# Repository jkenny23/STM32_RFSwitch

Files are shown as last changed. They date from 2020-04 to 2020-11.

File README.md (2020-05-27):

# STM32_RFSwitch
12V RF switch/DC relay controller (7 channels) and open-drain button press emulator (6 channels) with switchable USB2.0/USB3.0 ports with independent voltage/current monitoring. Includes 2 thermistor channels, and 2 spare ADC, 2 spare GPIO, and 1 spare GPI channel.

Zip file contains Gerbers ready for fab (2-up panel), and xlsx files contain BOM/component placement list also needed for fab by JLCPCB SMT service. Estimated cost is $61.77 for PCBA including DHL shipping (10 boards total, 5 panels), plus $18.12 for additional components from LCSC (through hole headers, inductor, USB connectors), and $16.86 for the STM32 "blue pill" microcontroller boards, for a total of $96.75 ($9.68 per board).

Usage:

RF Switch: r[1-7]

USB2.0 Power Control: l[1-2, 1=off, 2=on]

USB3.0 Power Control:  m[1-2, 1=off, 2=on]

Open Drain Output: o[1-6] l[level: 0 = open, 1 = low, default 0] d[delay, x0.1s, deafult 10 (1s)]

Cal R/W Mode: t[r/w] a[address: 0-999] d[data, unsigned int (0-65535)]

Version: v

Status: s

Soft Reset: z

Help (Prints this menu): ?

# Compatible RF Switches

| RF Switch P/N | RF Switch Mfg. | RF Switch Config | # IOs | CH/CL | Notes | RF Switch Datasheet | Approx. Price |
|---|---|---|---|---|---|---|---|
| 2SE1T11JB | Ducommun | SPDT | 2 | CL | | https://www.ducommun.com/pdf/mwcat/2s.pdf | $18.75-20 |
| 431-420823 | Dow-Key | SP3T | 3 | CH | Remove pull up resistor (R5/R15/R19/R25/R38/R47/R55) for IOs used | https://www.dowkey.com/wp-content/uploads/2015/06/_plk49_1_431461_Latching_CatalogPage.pdf | ~$36 (similar models) |

# Errata
The +/- input are swapped for the MCP6002 op-amp 2 (USB3.0 current measurement). The traces need to be cut and jumpered per the image below:

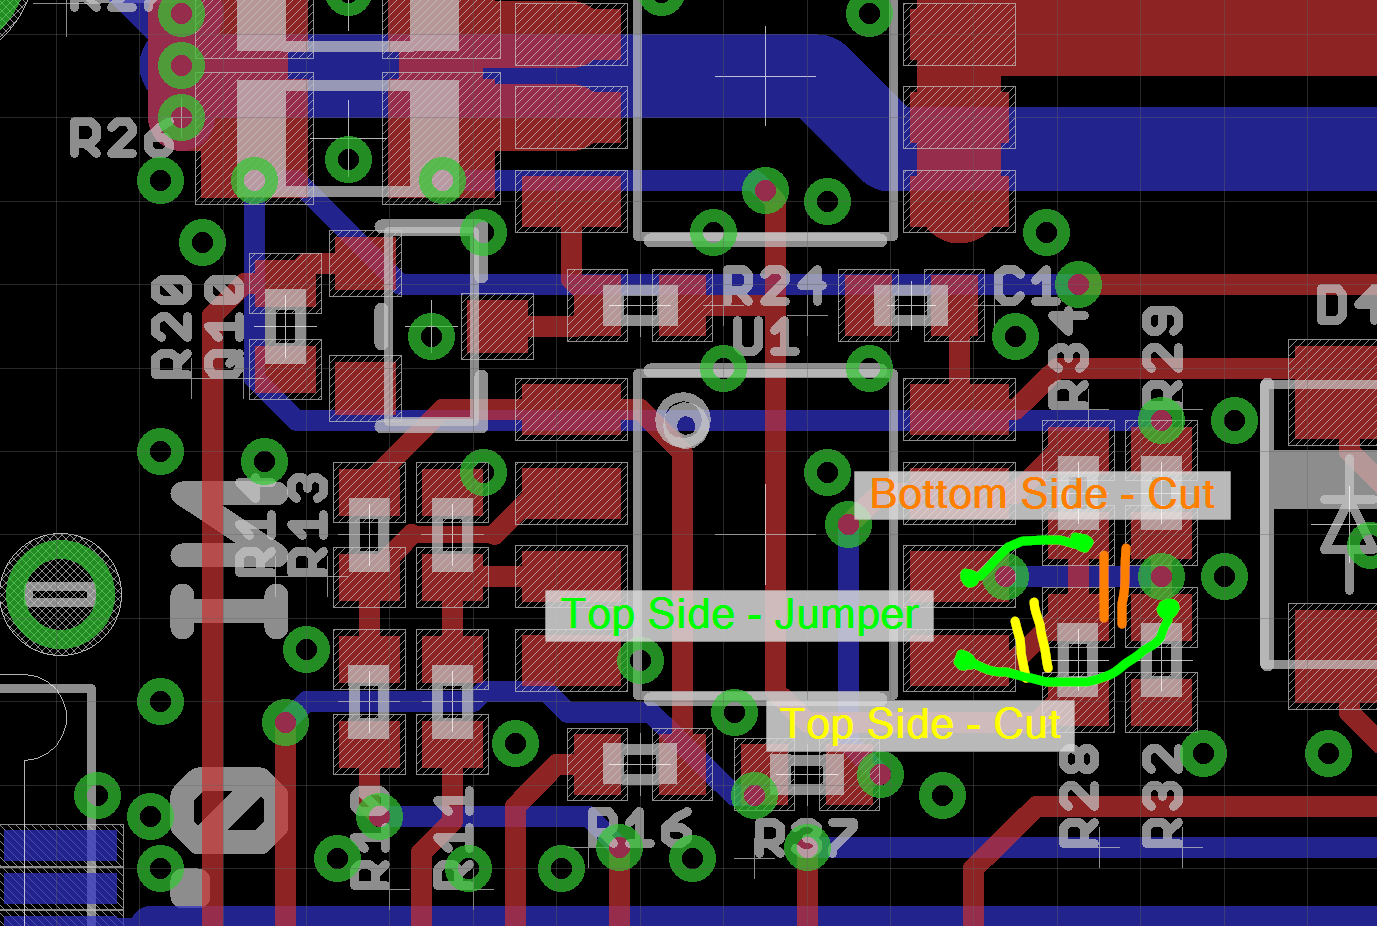
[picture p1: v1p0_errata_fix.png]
HW Fix for v1.0


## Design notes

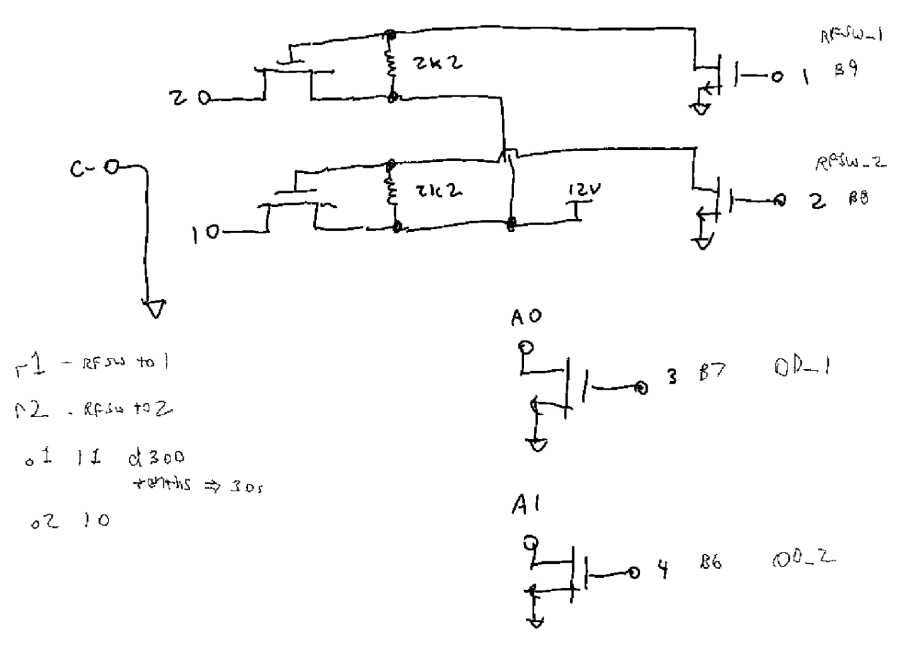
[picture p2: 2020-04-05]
RFSwitch_Schematic_Sketch.png

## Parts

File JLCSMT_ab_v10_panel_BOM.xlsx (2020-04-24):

Comment | Designator | Footprint | LCSC Part #（optional）
1.8k | R42, R60 | 0402_R | C4177
1k | R10, R11, R28, R29, R43, R46, R49, R51, R54, R57, R62, R69, R71, R74, R75, R76, R77, R78, R90, R92 | 0402_R | C11702
1u | C1, C3, C5, C11, C16, C17, C18, C20, C21, C23, C24, C25, C26, C33 | 0402_C | C52923
2.7k | R40, R67 | 0402_R | C13167
2N7002 | Q4, Q10, Q15, Q17, Q19, Q20, Q22, Q24, Q25, Q27, Q28, Q29, Q30, Q31, Q32, Q35 | SOT-23 | C8545
4.7u | C19, C22 | 0402_C | C23733
8.2k | R3, R21, R64, R88 | 0402_R | C25924
10k | R1, R2, R4, R5, R6, R9, R12, R15, R16, R17, R19, R20, R22, R23, R24, R25, R30, R31, R36, R37, R38, R41, R44, R45, R47, R48, R50, R52, R53, R55, R56, R59, R63, R65, R79, R80, R81, R82, R83, R84, R85, R87, R89, R95, R96, R97, R98, R99, R100, R101, R102, R103, R104, R105, R106, R107, R108, R109, R110, R111, R112, R114 | 0402_R | C25744
10n | C4, C14, C34, C35 | 0402_C | C15195
10u | C7, C8, C29, C30 | 0603_C | C19702
10u | C13, C15, C31, C32 | 0805_C | C15850
20k | R13, R14, R32, R34, R35, R68, R70, R72, R91, R93 | 0402_R | C25765
22n | C2, C6, C10, C36, C37, C38 | 0402_C | C1532
33k | R33, R113 | 0402_R | C25779
51k | R39, R66 | 0402_R | C25794
100m | R7, R8, R26, R27, R61, R73, R86, R94 | 1206_R | C25334
100n | C9, C12, C27, C28 | 0402_C | C1525
120 | R18, R58 | 0402_R | C25079
AO3400A | Q2, Q6, Q8, Q12, Q14, Q18, Q23, Q36, Q38, Q40, Q42, Q44, Q46, Q48 | SOT-23 | C20917
AO3401A | Q1, Q5, Q7, Q11, Q13, Q16, Q21, Q33, Q37, Q39, Q41, Q43, Q45, Q47 | SOT-23 | C15127
AO4407A | Q3, Q9, Q26, Q34 | SOIC-8 | C16072
B5817W | D1, D5, D6, D10, D12, D13, D14, D22, D23, D24, D25, D26, D27, D28 | SOD123 | C8598
CJ431 | U2, U6 | SOT-23 | C3113
FP6291 | U4, U9 | SOT-23-6 | C18701
MCP6002SOIC | U1, U10 | SOIC-8 | C7377
SS14 | D2, D3, D4, D15, D16, D17 | SMA | C2480
SS34 | D7, D8, D9, D11, D18, D19, D20, D21 | SMA | C8678

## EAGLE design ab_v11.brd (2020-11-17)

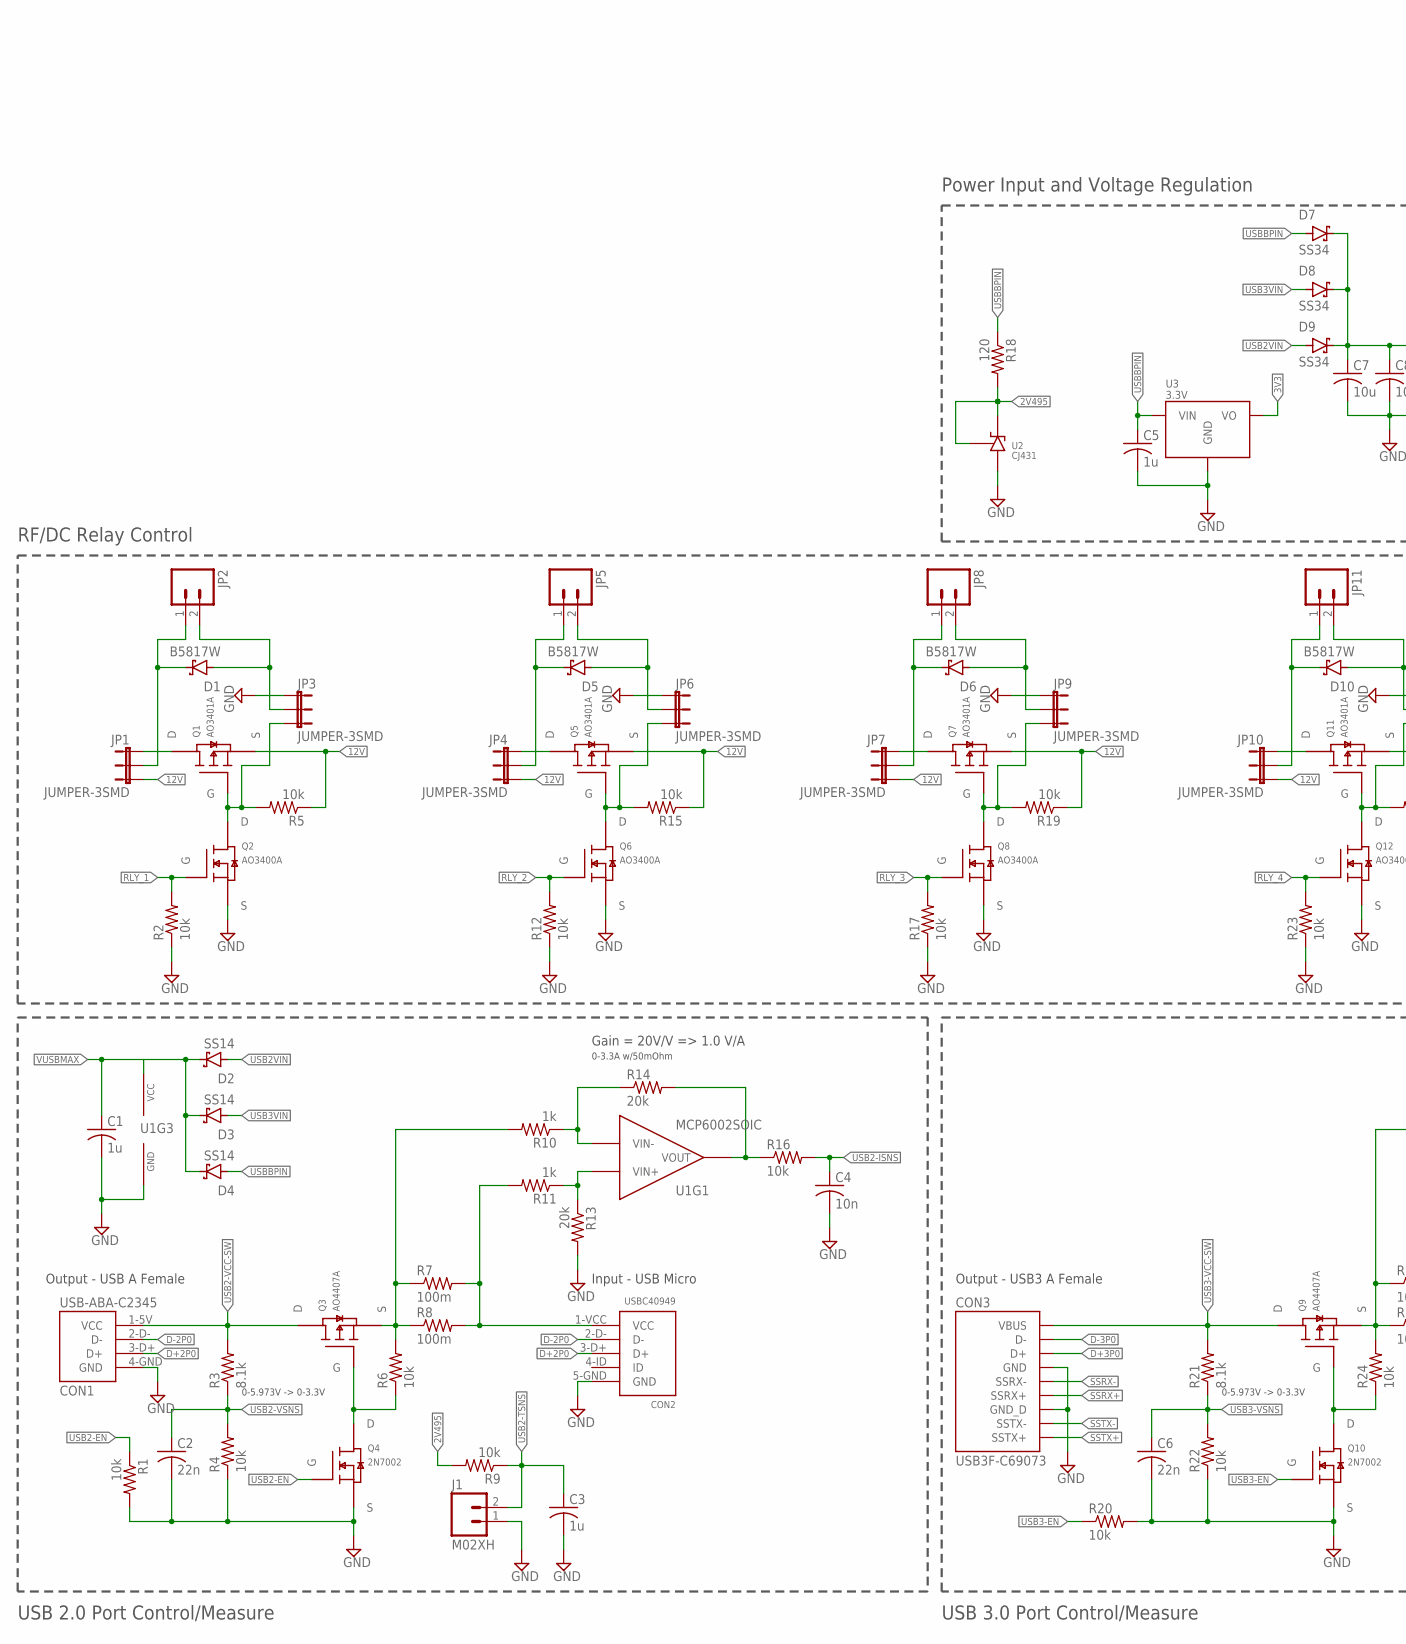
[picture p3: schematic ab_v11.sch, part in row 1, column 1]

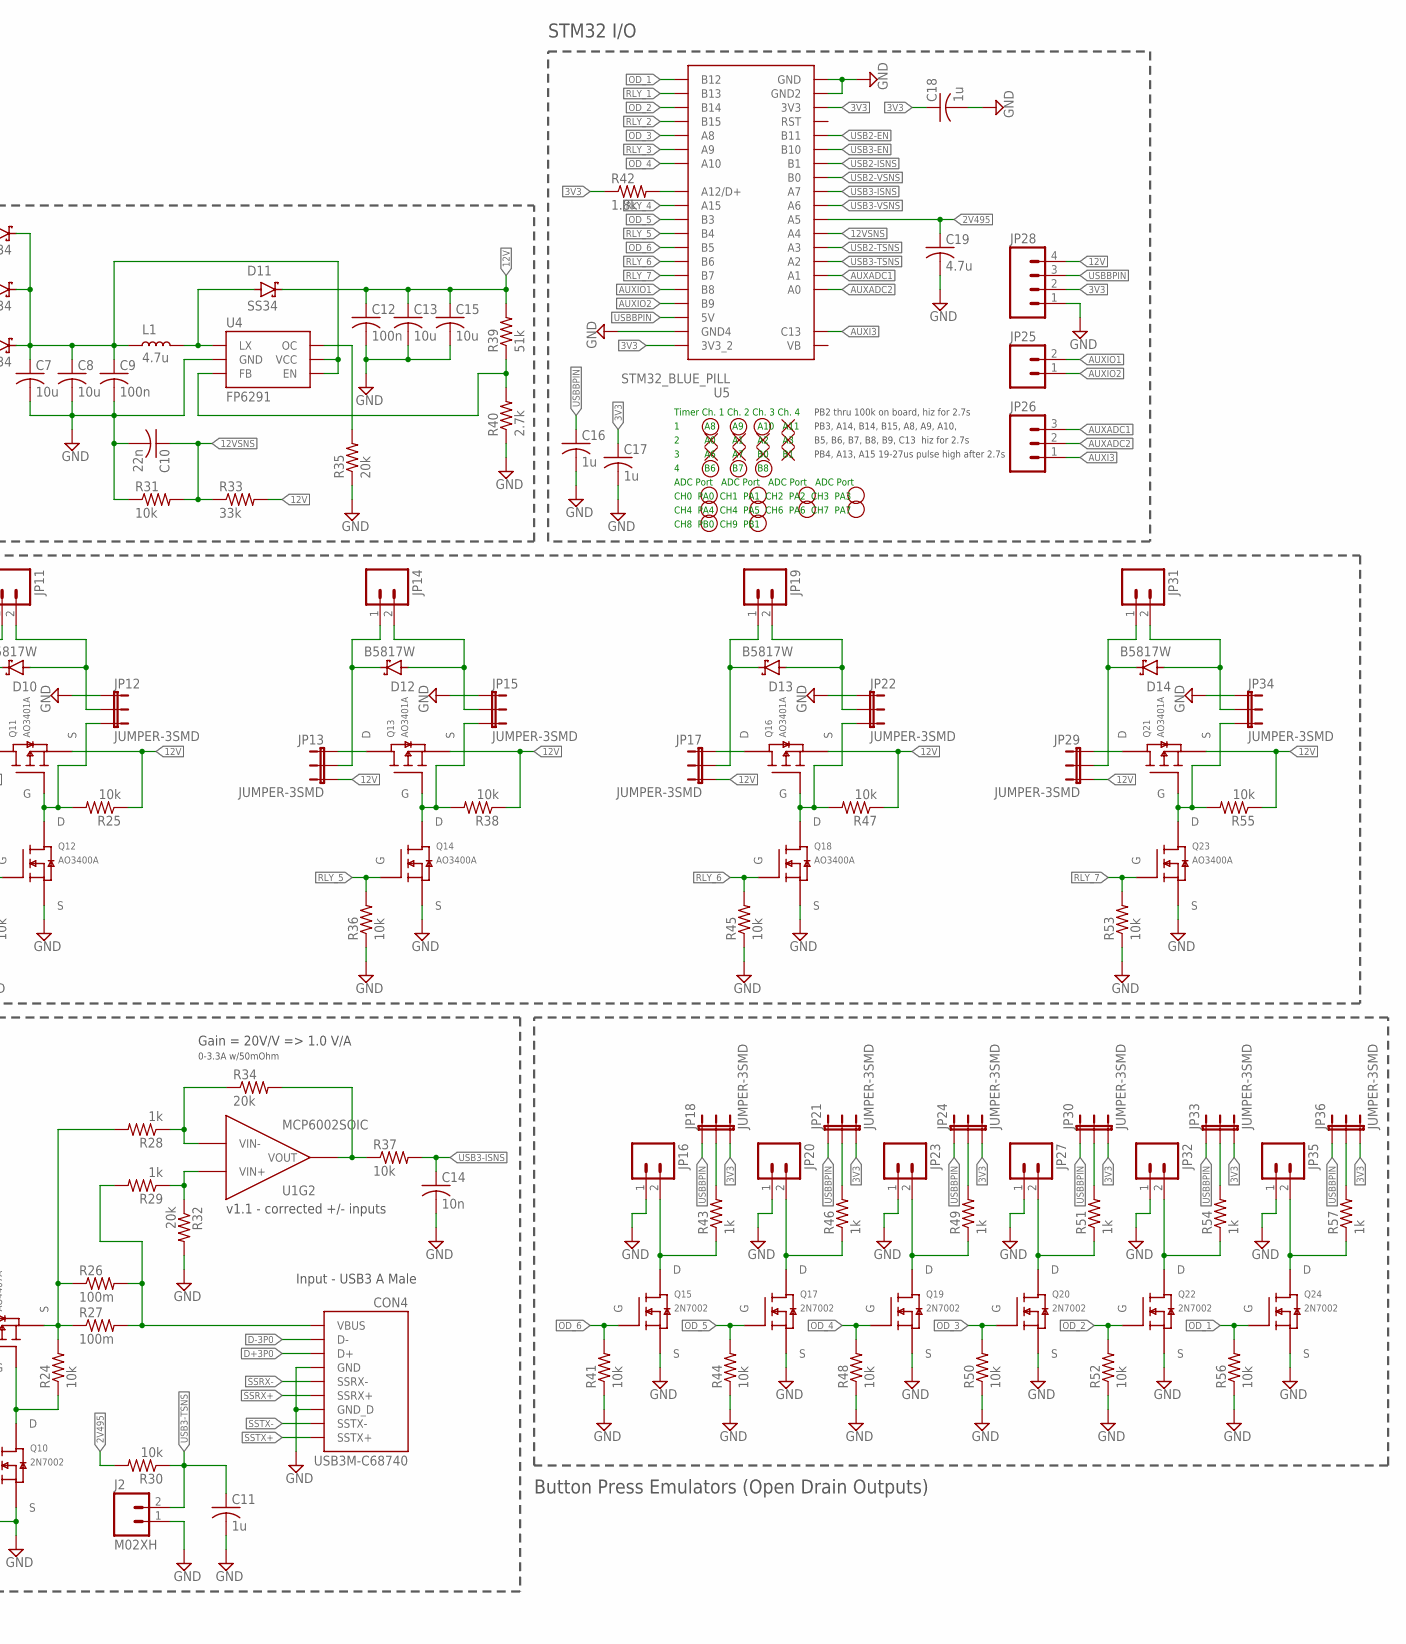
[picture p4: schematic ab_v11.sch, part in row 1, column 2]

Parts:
C1, C3, C5, C11, C16, C17, C18: 1u; C0402
C2, C6, C10: 22n; C0402
C4, C14: 10n; C0402
C7, C8: 10u; C0603
C9, C12: 100n; C0402
C13, C15: 10u; C0805
C19: 4.7u; C0402
CON1: USB-ABA-C2345; USB_A_C2345
CON2: USBC40949; MICRO_USB-B_C40949
CON3: USB3F-C69073; USB3-F-C69073
CON4: USB3M-C68740; USB3-M-C68740
D1, D5, D6, D10, D12, D13, D14: B5817W; SOD123W
D2, D3, D4: SS14; SMA
D7, D8, D9, D11: SS34; SMA
J1, J2: M02XH; B2B-XH-A
JP1, JP3, JP4, JP6, JP7, JP9, JP10, JP12, JP13, JP15, JP17, JP18, JP21, JP22, JP24, JP29, JP30, JP33, JP34, JP36: JUMPER-3SMD; SJ_3
JP2, JP5, JP8, JP11, JP14, JP16, JP19, JP20, JP23, JP25, JP27, JP31, JP32, JP35: M02PTH; 1X02
JP26: M03PTH; 1X03
JP28: M04PTH; 1X04
L1: 4.7u; INDUCTOR_6X6
Q1, Q5, Q7, Q11, Q13, Q16, Q21: AO3401A; SOT23
Q2, Q6, Q8, Q12, Q14, Q18, Q23: AO3400A; SOT23
Q3, Q9: AO4407A; 8-SOIC
Q4, Q10, Q15, Q17, Q19, Q20, Q22, Q24: 2N7002; SOT23
R1, R2, R4, R5, R6, R9, R12, R15, R16, R17, R19, R20, R22, R23, R24, R25, R30, R31, R36, R37, R38, R41, R44, R45, R47, R48, R50, R52, R53, R55, R56: 10k; R0402
R3, R21: 8.1k; R0402
R7, R8, R26, R27: 100m; R1206
R10, R11, R28, R29, R43, R46, R49, R51, R54, R57: 1k; R0402
R13, R14, R32, R34, R35: 20k; R0402
R18: 120; R0402
R33: 33k; R0402
R39: 51k; R0402
R40: 2.7k; R0402
R42: 1.8k; R0402
U1: MCP6002SOIC; 8-SOIC
U2: CJ431; SOT23
U3: 3.3V; SOT-89
U4: FP6291; SOT23-6
U5: STM32_BLUE_PILL; STM32_BLUE_PILL_USABLE

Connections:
2V495: C19.1, R9.2, R18.2, R30.2, U2.1 (K), U2.2 (REF), U5.A5
3V3: C17.1, C18.1, JP18.3, JP21.3, JP24.3, JP28.2, JP30.3, JP33.3, JP36.3, R42.1, U3.1 (VO), U5.3V3, U5.3V3_2
12V: C12.1, C13.1, C15.1, D11.K (CATHODE), JP1.3, JP4.3, JP7.3, JP10.3, JP13.3, JP17.3, JP28.4, JP29.3, Q1.2 (S), Q5.2 (S), Q7.2 (S), Q11.2 (S), Q13.2 (S), Q16.2 (S), Q21.2 (S), R5.1, R15.1, R19.1, R25.1, R33.2, R38.1, R39.2, R47.1, R55.1
12VSNS: C10.1, R31.2, R33.1, U5.A4
AUXADC1: JP26.3, U5.A1
AUXADC2: JP26.2, U5.A0
AUXI3: JP26.1, U5.C13
AUXIO1: JP25.2, U5.B8
AUXIO2: JP25.1, U5.B9
BOOSTVCC: C7.1, C8.1, C9.1, D7.K (CATHODE), D8.K (CATHODE), D9.K (CATHODE), L1.1, U4.4 (EN), U4.5 (VCC)
D+2P0: CON1.3-D+ (D+), CON2.3-D+ (D+)
D+3P0: CON3.3-D+ (D+), CON4.3-D+ (D+)
D-2P0: CON1.2-D- (D-), CON2.2-D- (D-)
D-3P0: CON3.2-D- (D-), CON4.2-D- (D-)
FB: R39.1, R40.2, U4.3 (FB)
GND: C1.2, C2.2, C3.2, C4.2, C5.2, C6.2, C7.2, C8.2, C9.2, C10.2, C11.2, C12.2, C13.2, C14.2, C15.2, C16.2, C17.2, C18.2, C19.2, CON1.4-GND (GND), CON2.5-GND (GND), CON3.4-GND (GND), CON3.7-GND (GND_D), CON4.4-GND (GND), CON4.7-GNDD (GND_D), J1.1, J2.1, JP3.1, JP6.1, JP9.1, JP12.1, JP15.1, JP16.1, JP20.1, JP22.1, JP23.1, JP27.1, JP28.1, JP32.1, JP34.1, JP35.1, Q2.2 (S), Q4.2 (S), Q6.2 (S), Q8.2 (S), Q10.2 (S), Q12.2 (S), Q14.2 (S), Q15.2 (S), Q17.2 (S), Q18.2 (S), Q19.2 (S), Q20.2 (S), Q22.2 (S), Q23.2 (S), Q24.2 (S), R1.2, R2.1, R4.1, R12.1, R13.2, R17.1, R20.2, R22.1, R23.1, R31.1, R32.2, R35.1, R36.1, R40.1, R41.1, R44.1, R45.1, R48.1, R50.1, R52.1, R53.1, R56.1, U1.4 (GND), U2.3 (A), U3.2 (GND), U3.2@1 (GND), U4.2 (GND), U5.GND, U5.GND2, U5.GND4
unnamed: JP16.2, Q15.3 (D), R43.1
unnamed: Q9.4 (G), Q10.3 (D), R24.1
unnamed: R10.1, R14.1, U1.2 (VIN-)
unnamed: R11.1, R13.1, U1.3 (VIN+)
unnamed: JP21.2, R46.2
unnamed: JP18.2, R43.2
unnamed: Q3.4 (G), Q4.3 (D), R6.1
unnamed: JP20.2, Q17.3 (D), R46.1
unnamed: JP24.2, R49.2
unnamed: JP23.2, Q19.3 (D), R49.1
unnamed: JP30.2, R51.2
unnamed: JP27.2, Q20.3 (D), R51.1
unnamed: JP33.2, R54.2
unnamed: JP32.2, Q22.3 (D), R54.1
unnamed: JP36.2, R57.2
unnamed: R28.1, R34.1, U1.6 (VIN-)
unnamed: R29.1, R32.1, U1.5 (VIN+)
unnamed: JP35.2, Q24.3 (D), R57.1
unnamed: JP6.3, Q5.1 (G), Q6.3 (D), R15.2
unnamed: R42.2, U5.A12 (A12/D+)
OC: R35.2, U4.6 (OC)
OD_1: Q24.1 (G), R56.2, U5.B12
OD_2: Q22.1 (G), R52.2, U5.B14
OD_3: Q20.1 (G), R50.2, U5.A8
OD_4: Q19.1 (G), R48.2, U5.A10
OD_5: Q17.1 (G), R44.2, U5.B3
OD_6: Q15.1 (G), R41.2, U5.B5
RLY1-SW: D1.K (CATHODE), JP1.2, JP2.1
RLY1-SW1: D5.K (CATHODE), JP4.2, JP5.1
RLY1-SW2: D6.K (CATHODE), JP7.2, JP8.1
RLY1-SW3: D10.K (CATHODE), JP10.2, JP11.1
RLY1-SW4: D12.K (CATHODE), JP13.2, JP14.1
RLY1-SW5: D13.K (CATHODE), JP17.2, JP19.1
RLY1-SW6: D14.K (CATHODE), JP29.2, JP31.1
RLY1D: JP1.1, Q1.3 (D)
RLY1D1: JP4.1, Q5.3 (D)
RLY1D2: JP7.1, Q7.3 (D)
RLY1D3: JP10.1, Q11.3 (D)
RLY1D4: JP13.1, Q13.3 (D)
RLY1D5: JP17.1, Q16.3 (D)
RLY1D6: JP29.1, Q21.3 (D)
RLY1DG: JP3.3, Q1.1 (G), Q2.3 (D), R5.2
RLY1DG2: JP9.3, Q7.1 (G), Q8.3 (D), R19.2
RLY1DG3: JP12.3, Q11.1 (G), Q12.3 (D), R25.2
RLY1DG4: JP15.3, Q13.1 (G), Q14.3 (D), R38.2
RLY1DG5: JP22.3, Q16.1 (G), Q18.3 (D), R47.2
RLY1DG6: JP34.3, Q21.1 (G), Q23.3 (D), R55.2
RLY1SPLY: D1.A (ANODE), JP2.2, JP3.2
RLY1SPLY1: D5.A (ANODE), JP5.2, JP6.2
RLY1SPLY2: D6.A (ANODE), JP8.2, JP9.2
RLY1SPLY3: D10.A (ANODE), JP11.2, JP12.2
RLY1SPLY4: D12.A (ANODE), JP14.2, JP15.2
RLY1SPLY5: D13.A (ANODE), JP19.2, JP22.2
RLY1SPLY6: D14.A (ANODE), JP31.2, JP34.2
RLY_1: Q2.1 (G), R2.2, U5.B13
RLY_2: Q6.1 (G), R12.2, U5.B15
RLY_3: Q8.1 (G), R17.2, U5.A9
RLY_4: Q12.1 (G), R23.2, U5.A15
RLY_5: Q14.1 (G), R36.2, U5.B4
RLY_6: Q18.1 (G), R45.2, U5.B6
RLY_7: Q23.1 (G), R53.2, U5.B7
SSRX+: CON3.6-SSRX+ (SSRX+), CON4.6-SSRX+ (SSRX+)
SSRX-: CON3.5-SSRX- (SSRX-), CON4.5-SSRX- (SSRX-)
SSTX+: CON3.9-SSTX+ (SSTX+), CON4.9-SSTX+ (SSTX+)
SSTX-: CON3.8-SSTX- (SSTX-), CON4.8-SSTX- (SSTX-)
SW: D11.A (ANODE), L1.2, U4.1 (LX)
USB2-EN: Q4.1 (G), R1.1, U5.B11
USB2-ISNS: C4.1, R16.2, U5.B1
USB2-ISNS-R: R14.2, R16.1, U1.1 (VOUT)
USB2-TSNS: C3.1, J1.2, R9.1, U5.A3
USB2-VCC-SW: CON1.1-5V (VCC), Q3.5 (D), Q3.6 (D), Q3.7 (D), Q3.8 (D), R3.2
USB2-VSNS: C2.1, R3.1, R4.2, U5.B0
USB2VIN: CON2.1-VCC (VCC), D2.A (ANODE), D9.A (ANODE), R7.2, R8.2, R11.2
USB3-EN: Q10.1 (G), R20.1, U5.B10
USB3-ISNS: C14.1, R37.2, U5.A7
USB3-ISNS-R: R34.2, R37.1, U1.7 (VOUT)
USB3-TSNS: C11.1, J2.2, R30.1, U5.A2
USB3-VCC-SW: CON3.1-VBUS (VBUS), Q9.5 (D), Q9.6 (D), Q9.7 (D), Q9.8 (D), R21.2
USB3-VSNS: C6.1, R21.1, R22.2, U5.A6
USB3OUTVCC: Q9.1 (S), Q9.2 (S), Q9.3 (S), R24.2, R26.1, R27.1, R28.2
USB3VIN: CON4.1-VBUS (VBUS), D3.A (ANODE), D8.A (ANODE), R26.2, R27.2, R29.2
USBBPIN: C5.1, C16.1, D4.A (ANODE), D7.A (ANODE), JP18.1, JP21.1, JP24.1, JP28.3, JP30.1, JP33.1, JP36.1, R18.1, U3.3 (VIN), U5.5V
USBOUTVCC: Q3.1 (S), Q3.2 (S), Q3.3 (S), R6.2, R7.1, R8.1, R10.2
VUSBMAX: C1.1, D2.K (CATHODE), D3.K (CATHODE), D4.K (CATHODE), U1.8 (VCC)

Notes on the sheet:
Gain = 20V/V => 1.0 V/A
0-3.3A w/50mOhm
0-5.973V -> 0-3.3V
STM32 I/O
Timer Ch. 1 Ch. 2 Ch. 3 Ch. 4
1 A8 A9 A10 A11
2 A0 A1 A2 A3
3 A6 A7 B0 B1
4 B6 B7 B8
ADC Port ADC Port ADC Port ADC Port
CH0 PA0 CH1 PA1 CH2 PA2 CH3 PA3
CH4 PA4 CH4 PA5 CH6 PA6 CH7 PA7
CH8 PB0 CH9 PB1
PB2 thru 100k on board, hiz for 2.7s
PB3, A14, B14, B15, A8, A9, A10,
PB4, A13, A15 19-27us pulse high after 2.7s
B5, B6, B7, B8, B9, C13 hiz for 2.7s
USB 2.0 Port Control/Measure
Power Input and Voltage Regulation
Button Press Emulators (Open Drain Outputs)
Input - USB Micro
Output - USB A Female
USB 3.0 Port Control/Measure
Input - USB3 A Male
Output - USB3 A Female
RF/DC Relay Control
v1.1 - corrected +/- inputs

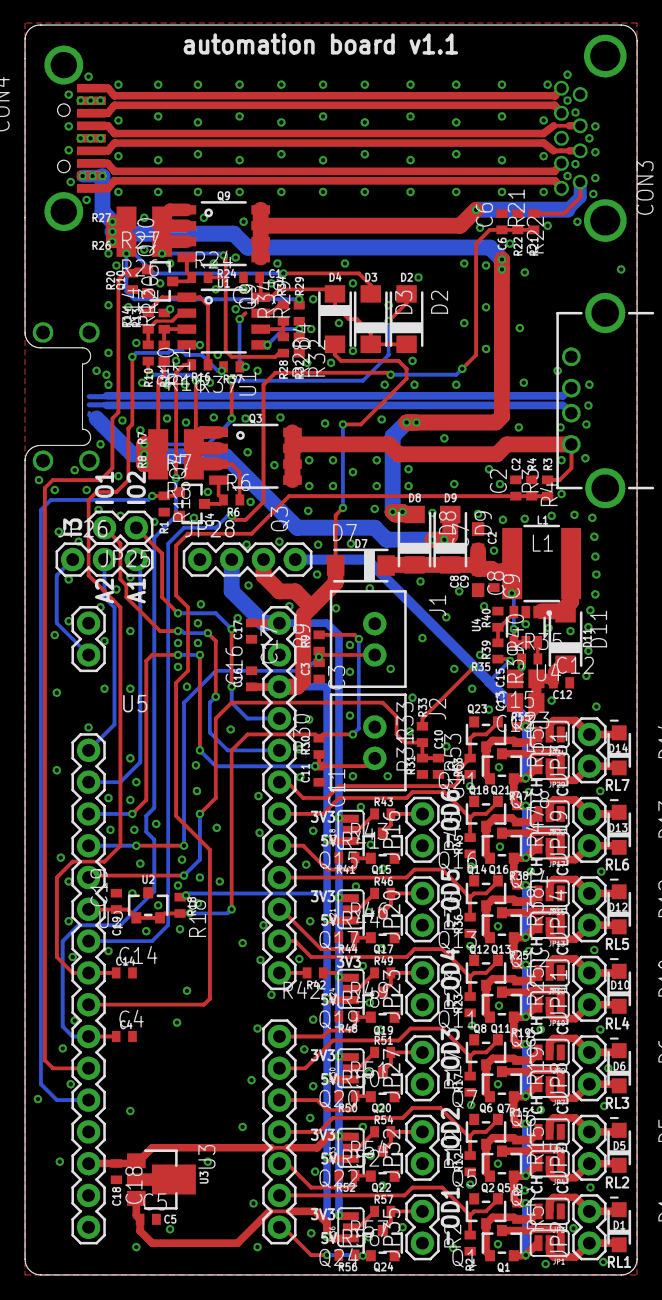
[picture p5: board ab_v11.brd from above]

Board: 2 copper layers, 48.9 x 99.9 mm, 162 parts (1 on the bottom side), 100 nets.

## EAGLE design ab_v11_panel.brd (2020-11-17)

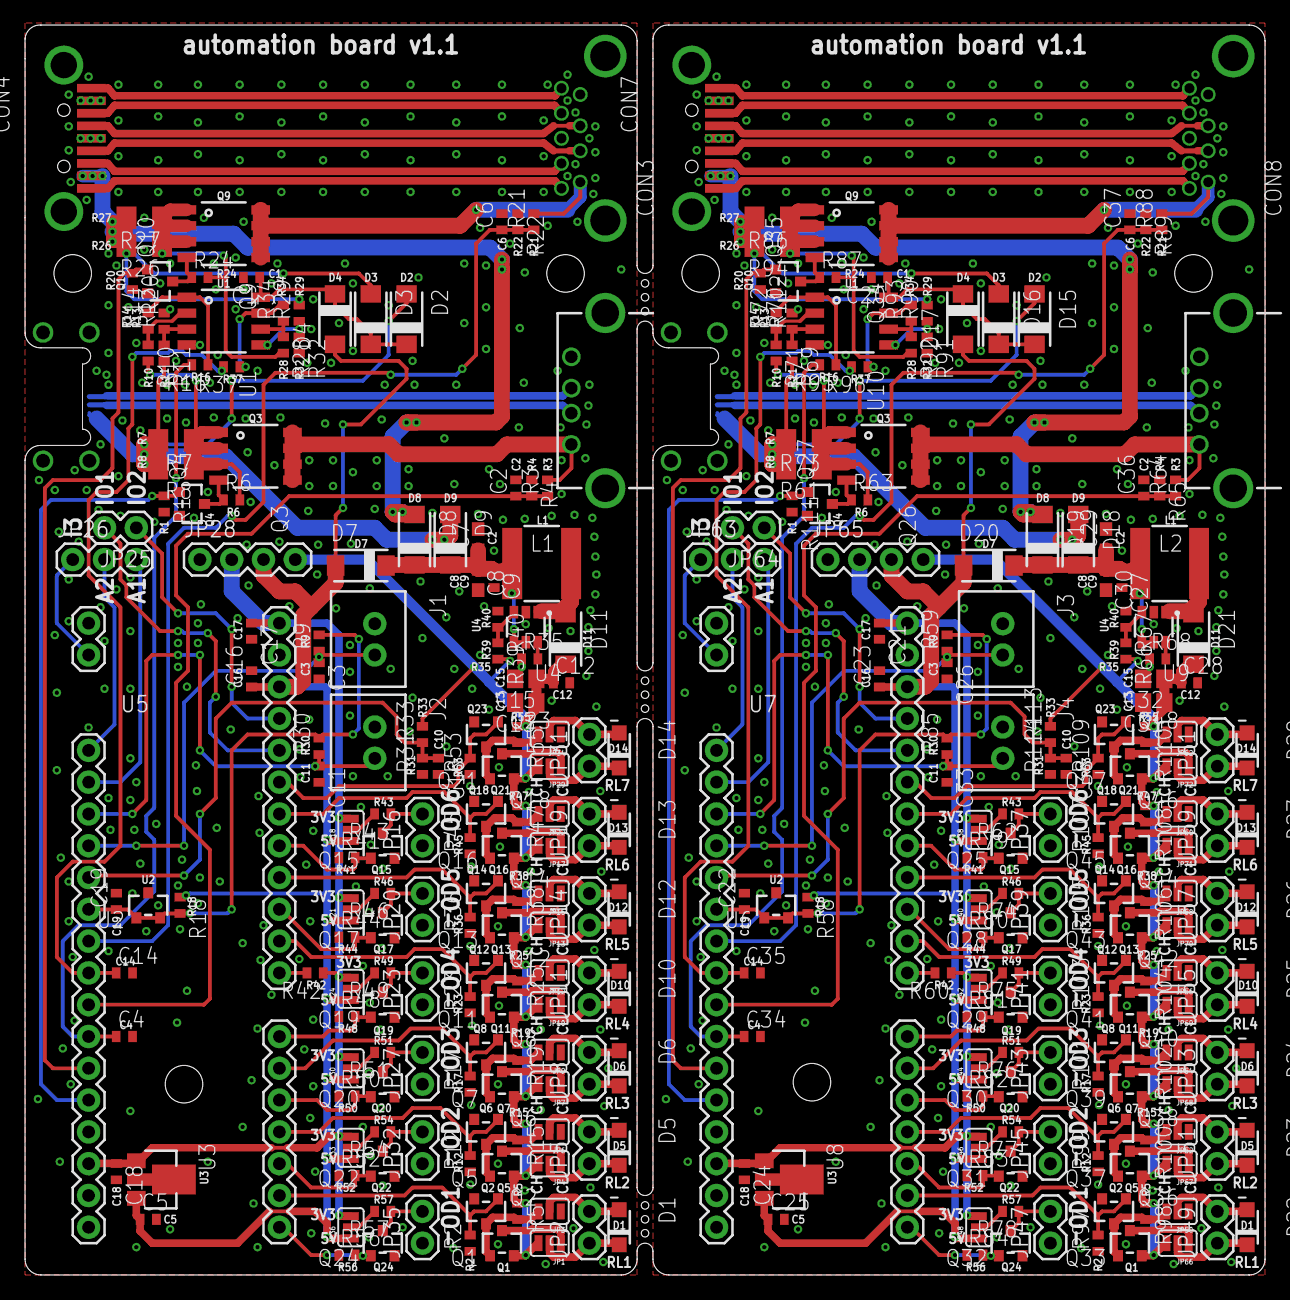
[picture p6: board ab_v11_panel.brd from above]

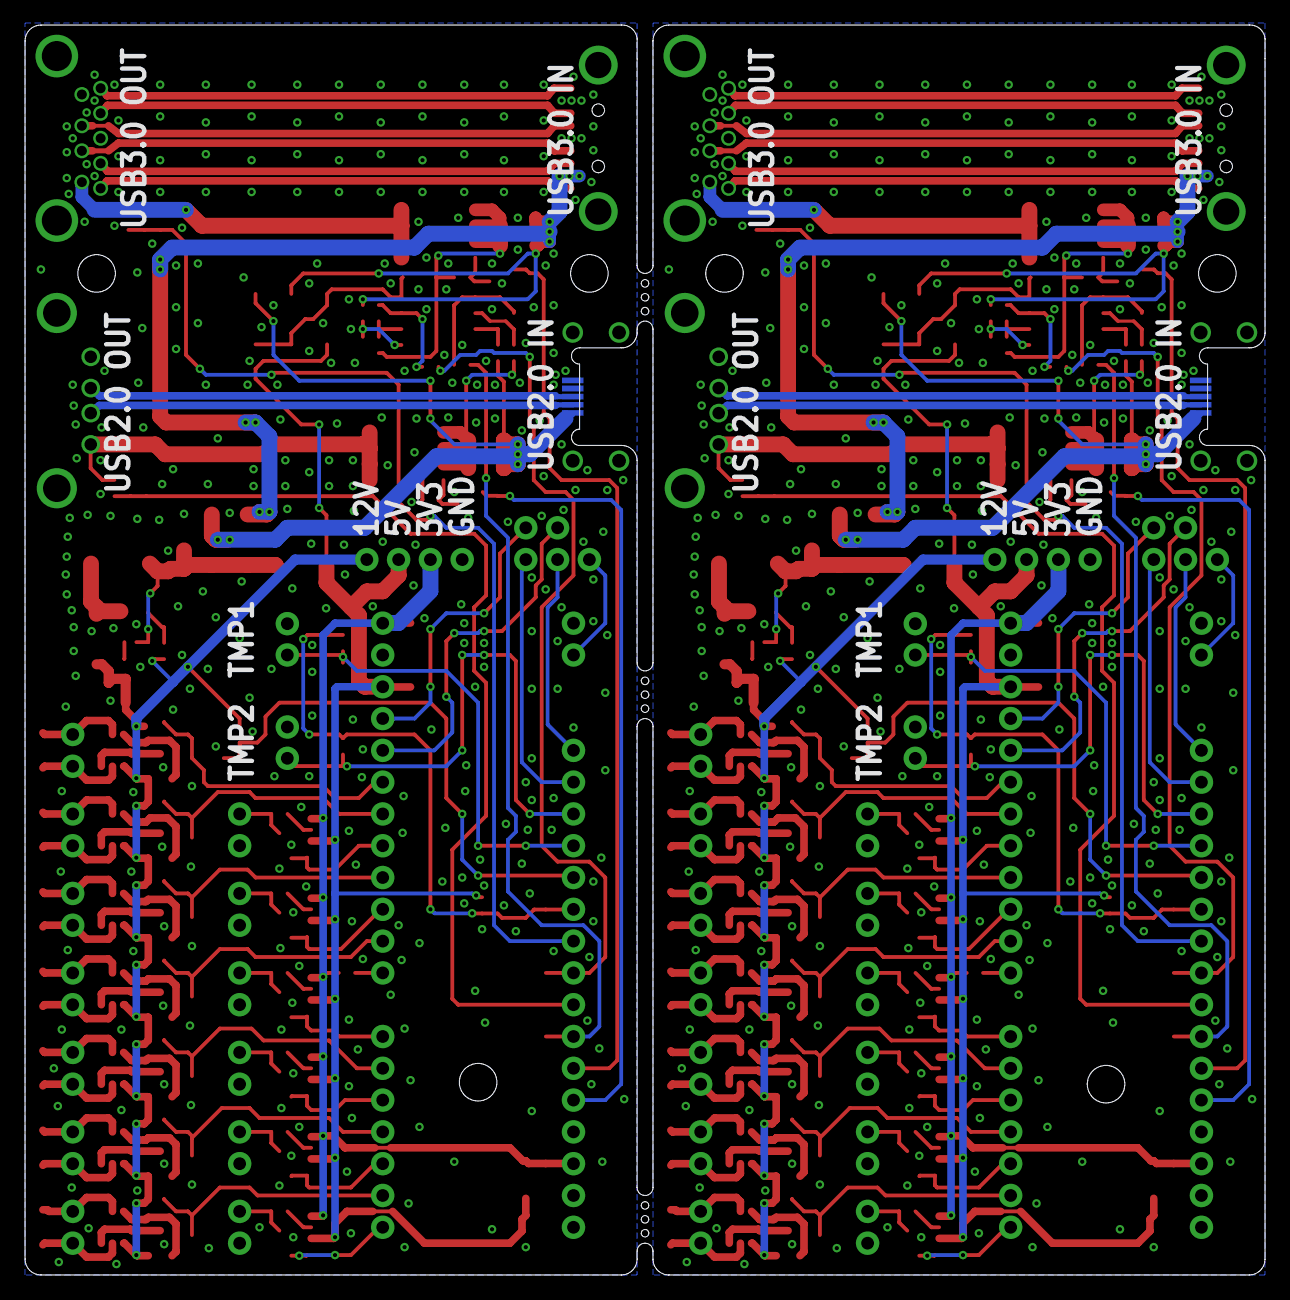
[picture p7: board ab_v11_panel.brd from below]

Board: 2 copper layers, 99.1 x 99.9 mm, 324 parts (2 on the bottom side), 200 nets.

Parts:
C1, C3, C5, C11, C16, C17, C18, C20, C21, C23, C24, C25, C26, C33: 1u; C0402
C2, C6, C10, C36, C37, C38: 22n; C0402
C4, C14, C34, C35: 10n; C0402
C7, C8, C29, C30: 10u; C0603
C9, C12, C27, C28: 100n; C0402
C13, C15, C31, C32: 10u; C0805
C19, C22: 4.7u; C0402
CON1, CON6: USB-ABA-C2345; USB_A_C2345
CON2, CON5: USBC40949; MICRO_USB-B_C40949
CON3, CON8: USB3F-C69073; USB3-F-C69073
CON4, CON7: USB3M-C68740; USB3-M-C68740
D1, D5, D6, D10, D12, D13, D14, D22, D23, D24, D25, D26, D27, D28: B5817W; SOD123W
D2, D3, D4, D15, D16, D17: SS14; SMA
D7, D8, D9, D11, D18, D19, D20, D21: SS34; SMA
J1, J2, J3, J4: M02XH; B2B-XH-A
JP1, JP3, JP4, JP6, JP7, JP9, JP10, JP12, JP13, JP15, JP17, JP18, JP21, JP22, JP24, JP29, JP30, JP33, JP34, JP36, JP38, JP40, JP42, JP44, JP46, JP48, JP50, JP52, JP54, JP56, JP58, JP60, JP62, JP66, JP67, JP68, JP69, JP70, JP71, JP72: JUMPER-3SMD; SJ_3
JP2, JP5, JP8, JP11, JP14, JP16, JP19, JP20, JP23, JP25, JP27, JP31, JP32, JP35, JP37, JP39, JP41, JP43, JP45, JP47, JP49, JP51, JP53, JP55, JP57, JP59, JP61, JP64: 1X02
JP26, JP63: 1X03
JP28, JP65: 1X04
L1, L2: 4.7u; INDUCTOR_6X6
Q1, Q5, Q7, Q11, Q13, Q16, Q21, Q33, Q37, Q39, Q41, Q43, Q45, Q47: AO3401A; SOT23
Q2, Q6, Q8, Q12, Q14, Q18, Q23, Q36, Q38, Q40, Q42, Q44, Q46, Q48: AO3400A; SOT23
Q3, Q9, Q26, Q34: AO4407A; 8-SOIC
Q4, Q10, Q15, Q17, Q19, Q20, Q22, Q24, Q25, Q27, Q28, Q29, Q30, Q31, Q32, Q35: 2N7002; SOT23
R1, R2, R4, R5, R6, R9, R12, R15, R16, R17, R19, R20, R22, R23, R24, R25, R30, R31, R36, R37, R38, R41, R44, R45, R47, R48, R50, R52, R53, R55, R56, R59, R63, R65, R79, R80, R81, R82, R83, R84, R85, R87, R89, R95, R96, R97, R98, R99, R100, R101, R102, R103, R104, R105, R106, R107, R108, R109, R110, R111, R112, R114: 10k; R0402
R3, R21, R64, R88: 8.1k; R0402
R7, R8, R26, R27, R61, R73, R86, R94: 100m; R1206
R10, R11, R28, R29, R43, R46, R49, R51, R54, R57, R62, R69, R71, R74, R75, R76, R77, R78, R90, R92: 1k; R0402
R13, R14, R32, R34, R35, R68, R70, R72, R91, R93: 20k; R0402
R18, R58: 120; R0402
R33, R113: 33k; R0402
R39, R66: 51k; R0402
R40, R67: 2.7k; R0402
R42, R60: 1.8k; R0402
U1, U10: MCP6002SOIC; 8-SOIC
U2, U6: CJ431; SOT23
U3, U8: 3.3V; SOT-89
U4, U9: FP6291; SOT23-6
U5, U7: STM32_BLUE_PILL; STM32_BLUE_PILL_USABLE

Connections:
2V1: C22.1, R58.2, R59.2, R85.2, U6.1, U6.2, U7.A5
2V495: C19.1, R9.2, R18.2, R30.2, U2.1, U2.2, U5.A5
3V1: C21.1, C24.1, JP38.3, JP40.3, JP42.3, JP44.3, JP46.3, JP48.3, JP65.2, R60.1, U7.3V3, U7.3V3_2, U8.1
3V3: C17.1, C18.1, JP18.3, JP21.3, JP24.3, JP28.2, JP30.3, JP33.3, JP36.3, R42.1, U3.1, U5.3V3, U5.3V3_2
12V: C12.1, C13.1, C15.1, D11.K, JP1.3, JP4.3, JP7.3, JP10.3, JP13.3, JP17.3, JP28.4, JP29.3, Q1.2, Q5.2, Q7.2, Q11.2, Q13.2, Q16.2, Q21.2, R5.1, R15.1, R19.1, R25.1, R33.2, R38.1, R39.2, R47.1, R55.1
12V1: C28.1, C31.1, C32.1, D21.K, JP65.4, JP66.3, JP67.3, JP68.3, JP69.3, JP70.3, JP71.3, JP72.3, Q33.2, Q37.2, Q39.2, Q41.2, Q43.2, Q45.2, Q47.2, R66.2, R98.1, R100.1, R102.1, R104.1, R106.1, R108.1, R110.1, R113.2
12VSNS: C10.1, R31.2, R33.1, U5.A4
12VSNS1: C38.1, R113.1, R114.2, U7.A4
AUXADC1: JP26.3, U5.A1
AUXADC2: JP26.2, U5.A0
AUXADC3: JP63.3, U7.A1
AUXADC4: JP63.2, U7.A0
AUXI1: JP63.1, U7.C13
AUXI3: JP26.1, U5.C13
AUXIO1: JP25.2, U5.B8
AUXIO2: JP25.1, U5.B9
AUXIO3: JP64.1, U7.B9
AUXIO4: JP64.2, U7.B8
BOOSTVCC: C7.1, C8.1, C9.1, D7.K, D8.K, D9.K, L1.1, U4.4, U4.5
BOOSTVCC1: C27.1, C29.1, C30.1, D18.K, D19.K, D20.K, L2.1, U9.4, U9.5
D+2P0: CON1.3-D+, CON2.3-D+
D+2P1: CON5.3-D+, CON6.3-D+
D+3P0: CON3.3-D+, CON4.3-D+
D+3P1: CON7.3-D+, CON8.3-D+
D-2P0: CON1.2-D-, CON2.2-D-
D-2P1: CON5.2-D-, CON6.2-D-
D-3P0: CON3.2-D-, CON4.2-D-
D-3P1: CON7.2-D-, CON8.2-D-
FB: R39.1, R40.2, U4.3
FB1: R66.1, R67.2, U9.3
GND: C1.2, C2.2, C3.2, C4.2, C5.2, C6.2, C7.2, C8.2, C9.2, C10.2, C11.2, C12.2, C13.2, C14.2, C15.2, C16.2, C17.2, C18.2, C19.2, CON1.4-GND, CON2.5-GND, CON3.4-GND, CON3.7-GND, CON4.4-GND, CON4.7-GNDD, J1.1, J2.1, JP3.1, JP6.1, JP9.1, JP12.1, JP15.1, JP16.1, JP20.1, JP22.1, JP23.1, JP27.1, JP28.1, JP32.1, JP34.1, JP35.1, Q2.2, Q4.2, Q6.2, Q8.2, Q10.2, Q12.2, Q14.2, Q15.2, Q17.2, Q18.2, Q19.2, Q20.2, Q22.2, Q23.2, Q24.2, R1.2, R2.1, R4.1, R12.1, R13.2, R17.1, R20.2, R22.1, R23.1, R31.1, R32.2, R35.1, R36.1, R40.1, R41.1, R44.1, R45.1, R48.1, R50.1, R52.1, R53.1, R56.1, U1.4, U2.3, U3.2, U3.2@1, U4.2, U5.GND, U5.GND2, U5.GND4
GND1: C20.2, C21.2, C22.2, C23.2, C24.2, C25.2, C26.2, C27.2, C28.2, C29.2, C30.2, C31.2, C32.2, C33.2, C34.2, C35.2, C36.2, C37.2, C38.2, CON5.5-GND, CON6.4-GND, CON7.4-GND, CON7.7-GNDD, CON8.4-GND, CON8.7-GND, J3.1, J4.1, JP37.1, JP39.1, JP41.1, JP43.1, JP45.1, JP47.1, JP50.1, JP52.1, JP54.1, JP56.1, JP58.1, JP60.1, JP62.1, JP65.1, Q25.2, Q27.2, Q28.2, Q29.2, Q30.2, Q31.2, Q32.2, Q35.2, Q36.2, Q38.2, Q40.2, Q42.2, Q44.2, Q46.2, Q48.2, R65.1, R67.1, R68.1, R70.2, R79.1, R80.1, R81.1, R82.1, R83.1, R84.1, R89.1, R91.2, R97.1, R99.1, R101.1, R103.1, R105.1, R107.1, R109.1, R111.2, R112.2, R114.1, U6.3, U7.GND, U7.GND2, U7.GND4, U8.2, U8.2@1, U9.2, U10.4
unnamed: JP16.2, Q15.3, R43.1
unnamed: Q9.4, Q10.3, R24.1
unnamed: R10.1, R14.1, U1.2
unnamed: R11.1, R13.1, U1.3
unnamed: JP21.2, R46.2
unnamed: JP18.2, R43.2
unnamed: Q3.4, Q4.3, R6.1
unnamed: JP20.2, Q17.3, R46.1
unnamed: JP24.2, R49.2
unnamed: JP23.2, Q19.3, R49.1
unnamed: JP30.2, R51.2
unnamed: JP27.2, Q20.3, R51.1
unnamed: JP33.2, R54.2
unnamed: JP32.2, Q22.3, R54.1
unnamed: JP36.2, R57.2
unnamed: R28.1, R34.1, U1.6
unnamed: R29.1, R32.1, U1.5
unnamed: JP35.2, Q24.3, R57.1
unnamed: R60.2, U7.A12
unnamed: JP6.3, Q5.1, Q6.3, R15.2
unnamed: JP38.2, R62.2
unnamed: Q26.4, Q27.3, R63.1
unnamed: R71.1, R72.1, U10.2
unnamed: R69.1, R70.1, U10.3
unnamed: JP37.2, Q25.3, R62.1
unnamed: R42.2, U5.A12
unnamed: JP40.2, R74.2
unnamed: JP39.2, Q28.3, R74.1
unnamed: JP42.2, R75.2
unnamed: JP41.2, Q29.3, R75.1
unnamed: JP44.2, R76.2
unnamed: JP43.2, Q30.3, R76.1
unnamed: JP46.2, R77.2
unnamed: JP45.2, Q31.3, R77.1
unnamed: JP48.2, R78.2
unnamed: JP47.2, Q32.3, R78.1
unnamed: Q34.4, Q35.3, R87.1
unnamed: R92.1, R93.1, U10.6
unnamed: R90.1, R91.1, U10.5
unnamed: JP52.3, Q37.1, Q38.3, R100.2
OC: R35.2, U4.6
OC1: R68.2, U9.6
OD_1: Q24.1, R56.2, U5.B12
OD_2: Q22.1, R52.2, U5.B14
OD_3: Q20.1, R50.2, U5.A8
OD_4: Q19.1, R48.2, U5.A10
OD_5: Q17.1, R44.2, U5.B3
OD_6: Q15.1, R41.2, U5.B5
OD_7: Q32.1, R84.2, U7.B12
OD_8: Q31.1, R83.2, U7.B14
OD_9: Q30.1, R82.2, U7.A8
OD_10: Q29.1, R81.2, U7.A10
OD_11: Q28.1, R80.2, U7.B3
OD_12: Q25.1, R79.2, U7.B5
RLY1-SW: D1.K, JP1.2, JP2.1
RLY1-SW1: D5.K, JP4.2, JP5.1
RLY1-SW2: D6.K, JP7.2, JP8.1
RLY1-SW3: D10.K, JP10.2, JP11.1
RLY1-SW4: D12.K, JP13.2, JP14.1
RLY1-SW5: D13.K, JP17.2, JP19.1
RLY1-SW6: D14.K, JP29.2, JP31.1
RLY1-SW7: D22.K, JP49.1, JP66.2
RLY1-SW8: D23.K, JP51.1, JP67.2
RLY1-SW9: D24.K, JP53.1, JP68.2
RLY1-SW10: D25.K, JP55.1, JP69.2
RLY1-SW11: D26.K, JP57.1, JP70.2
RLY1-SW12: D27.K, JP59.1, JP71.2
RLY1-SW13: D28.K, JP61.1, JP72.2
RLY1D: JP1.1, Q1.3
RLY1D1: JP4.1, Q5.3
RLY1D2: JP7.1, Q7.3
RLY1D3: JP10.1, Q11.3
RLY1D4: JP13.1, Q13.3
RLY1D5: JP17.1, Q16.3
RLY1D6: JP29.1, Q21.3
RLY1D7: JP66.1, Q33.3
RLY1D8: JP67.1, Q37.3
RLY1D9: JP68.1, Q39.3
RLY1D10: JP69.1, Q41.3
RLY1D11: JP70.1, Q43.3
RLY1D12: JP71.1, Q45.3
RLY1D13: JP72.1, Q47.3
RLY1DG: JP3.3, Q1.1, Q2.3, R5.2
RLY1DG1: JP50.3, Q33.1, Q36.3, R98.2
RLY1DG2: JP9.3, Q7.1, Q8.3, R19.2
RLY1DG3: JP12.3, Q11.1, Q12.3, R25.2
RLY1DG4: JP15.3, Q13.1, Q14.3, R38.2
RLY1DG5: JP22.3, Q16.1, Q18.3, R47.2
RLY1DG6: JP34.3, Q21.1, Q23.3, R55.2
RLY1DG7: JP54.3, Q39.1, Q40.3, R102.2
RLY1DG8: JP56.3, Q41.1, Q42.3, R104.2
RLY1DG9: JP58.3, Q43.1, Q44.3, R106.2
RLY1DG10: JP60.3, Q45.1, Q46.3, R108.2
RLY1DG11: JP62.3, Q47.1, Q48.3, R110.2
RLY1SPLY: D1.A, JP2.2, JP3.2
RLY1SPLY1: D5.A, JP5.2, JP6.2
RLY1SPLY2: D6.A, JP8.2, JP9.2
RLY1SPLY3: D10.A, JP11.2, JP12.2
RLY1SPLY4: D12.A, JP14.2, JP15.2
RLY1SPLY5: D13.A, JP19.2, JP22.2
RLY1SPLY6: D14.A, JP31.2, JP34.2
RLY1SPLY7: D22.A, JP49.2, JP50.2
RLY1SPLY8: D23.A, JP51.2, JP52.2
RLY1SPLY9: D24.A, JP53.2, JP54.2
RLY1SPLY10: D25.A, JP55.2, JP56.2
RLY1SPLY11: D26.A, JP57.2, JP58.2
RLY1SPLY12: D27.A, JP59.2, JP60.2
RLY1SPLY13: D28.A, JP61.2, JP62.2
RLY_1: Q2.1, R2.2, U5.B13
RLY_2: Q6.1, R12.2, U5.B15
RLY_3: Q8.1, R17.2, U5.A9
RLY_4: Q12.1, R23.2, U5.A15
RLY_5: Q14.1, R36.2, U5.B4
RLY_6: Q18.1, R45.2, U5.B6
RLY_7: Q23.1, R53.2, U5.B7
RLY_8: Q36.1, R97.2, U7.B13
RLY_9: Q38.1, R99.2, U7.B15
RLY_10: Q40.1, R101.2, U7.A9
RLY_11: Q42.1, R103.2, U7.A15
RLY_12: Q44.1, R105.2, U7.B4
RLY_13: Q46.1, R107.2, U7.B6
RLY_14: Q48.1, R109.2, U7.B7
SSRX+: CON3.6-SSRX+, CON4.6-SSRX+
SSRX+1: CON7.6-SSRX+, CON8.6-SSRX+
SSRX-: CON3.5-SSRX-, CON4.5-SSRX-
SSRX-1: CON7.5-SSRX-, CON8.5-SSRX-
SSTX+: CON3.9-SSTX+, CON4.9-SSTX+
SSTX+1: CON7.9-SSTX+, CON8.9-SSTX+
SSTX-: CON3.8-SSTX-, CON4.8-SSTX-
SSTX-1: CON7.8-SSTX-, CON8.8-SSTX-
SW: D11.A, L1.2, U4.1
SW1: D21.A, L2.2, U9.1
USB2-EN: Q4.1, R1.1, U5.B11
USB2-EN1: Q27.1, R111.1, U7.B11
USB2-ISNS: C4.1, R16.2, U5.B1
USB2-ISNS1: C34.1, R95.2, U7.B1
USB2-ISNS-R: R14.2, R16.1, U1.1
USB2-ISNS-R1: R72.2, R95.1, U10.1
USB2-TSNS: C3.1, J1.2, R9.1, U5.A3
USB2-TSNS1: C26.1, J3.2, R59.1, U7.A3
USB2-VCC-SW: CON1.1-5V, Q3.5, Q3.6, Q3.7, Q3.8, R3.2
USB2-VCC-SW1: CON6.1-5V, Q26.5, Q26.6, Q26.7, Q26.8, R64.2
USB2-VSNS: C2.1, R3.1, R4.2, U5.B0
USB2-VSNS1: C36.1, R64.1, R65.2, U7.B0
USB2VIN: CON2.1-VCC, D2.A, D9.A, R7.2, R8.2, R11.2
USB2VIN1: CON5.1-VCC, D15.A, D18.A, R61.2, R69.2, R73.2
USB3-EN: Q10.1, R20.1, U5.B10
USB3-EN1: Q35.1, R112.1, U7.B10
USB3-ISNS: C14.1, R37.2, U5.A7
USB3-ISNS1: C35.1, R96.2, U7.A7
USB3-ISNS-R: R34.2, R37.1, U1.7
USB3-ISNS-R1: R93.2, R96.1, U10.7
USB3-TSNS: C11.1, J2.2, R30.1, U5.A2
USB3-TSNS1: C33.1, J4.2, R85.1, U7.A2
USB3-VCC-SW: CON3.1-VBUS, Q9.5, Q9.6, Q9.7, Q9.8, R21.2
USB3-VCC-SW1: CON8.1-VBUS, Q34.5, Q34.6, Q34.7, Q34.8, R88.2
USB3-VSNS: C6.1, R21.1, R22.2, U5.A6
USB3-VSNS1: C37.1, R88.1, R89.2, U7.A6
USB3OUTVCC: Q9.1, Q9.2, Q9.3, R24.2, R26.1, R27.1, R28.2
USB3OUTVCC1: Q34.1, Q34.2, Q34.3, R86.1, R87.2, R92.2, R94.1
USB3VIN: CON4.1-VBUS, D3.A, D8.A, R26.2, R27.2, R29.2
USB3VIN1: CON7.1-VBUS, D16.A, D19.A, R86.2, R90.2, R94.2
USBBPIN: C5.1, C16.1, D4.A, D7.A, JP18.1, JP21.1, JP24.1, JP28.3, JP30.1, JP33.1, JP36.1, R18.1, U3.3, U5.5V
USBBPIN1: C23.1, C25.1, D17.A, D20.A, JP38.1, JP40.1, JP42.1, JP44.1, JP46.1, JP48.1, JP65.3, R58.1, U7.5V, U8.3
USBOUTVCC: Q3.1, Q3.2, Q3.3, R6.2, R7.1, R8.1, R10.2
USBOUTVCC1: Q26.1, Q26.2, Q26.3, R61.1, R63.2, R71.2, R73.1
VUSBMAX: C1.1, D2.K, D3.K, D4.K, U1.8
VUSBMAX1: C20.1, D15.K, D16.K, D17.K, U10.8

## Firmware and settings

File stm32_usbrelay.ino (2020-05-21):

/*
 *  This sketch sends ads1115 current sensor data via HTTP POST request to thingspeak server.
 *  It needs the following libraries to work (besides the esp8266 standard libraries supplied with the IDE):
 *
 *  - https://github.com/adafruit/Adafruit_ADS1X15
 *
 *  designed to run directly on esp8266-01 module, to where it can be uploaded using this marvelous piece of software:
 *
 *  https://github.com/esp8266/Arduino
 *
 *  2015 Tisham Dhar
 *  licensed under GNU GPL
 */
#include <string.h>
#include <stdio.h>
#include <stdlib.h>
#include <EEPROM.h>

#define HW_1P0
//#define BREADBOARD

#ifdef BREADBOARD
  #define RFSW_1 PB9
  #define RFSW_2 PB8
  #define OD_1 PB7
  #define OD_2 PB6
  #define RELAY PB5
#endif
#ifdef HW_1P0
  #define RFSW_1 PB13
  #define RFSW_2 PB15
  #define RFSW_3 PA9
  #define RFSW_4 PA15
  #define RFSW_5 PB4
  #define RFSW_6 PB6
  #define RFSW_7 PB7
  #define OD_1 PB12
  #define OD_2 PB14
  #define OD_3 PA8
  #define OD_4 PA10
  #define OD_5 PB3
  #define OD_6 PB5
  #define RELAY PB11 //USB2.0, 1=on, 0=off
  #define RELAY2 PB10 //USB3.0, 1=on, 0=off
  #define USB2ISNS PB1
  #define USB2VSNS PB0
  #define USB3ISNS PA7
  #define USB3VSNS PA6
  #define AIREF PA5
  #define V12V PA4
  #define TMP1 PA3
  #define TMP2 PA2
  #define AUXADC1 PA1
  #define AUXADC2 PA2
  #define AUXIO1 PB8
  #define AUXIO2 PB9
  #define AUXI13 PC13
#endif

#define DEF_LEVEL 0
#define DEF_RFPOS 1
#define DEF_DELAY 10
#define MIN_DELAY 1
#define MAX_DELAY 650

const char vers[] = "0.1-04302020"; 

//Initialize reference voltage with default until read out of EEPROM
#define RFSWDELAYINIT 50
volatile uint16 RFSWDELAY = RFSWDELAYINIT;
volatile uint32 tick = 0;
uint32 last_tick = 0;
uint32 last_ms_tick = 0;

uint8 level_1 = DEF_LEVEL;
uint8 last_level_1 = DEF_LEVEL;
uint16 delay_1 = DEF_DELAY;
uint8 level_2 = DEF_LEVEL;
uint8 last_level_2 = DEF_LEVEL;
uint16 delay_2 = DEF_DELAY;
#ifdef HW_1P0
  uint8 level_3 = DEF_LEVEL;
  uint8 last_level_3 = DEF_LEVEL;
  uint16 delay_3 = DEF_DELAY;
  uint8 level_4 = DEF_LEVEL;
  uint8 last_level_4 = DEF_LEVEL;
  uint16 delay_4 = DEF_DELAY;
  uint8 level_5 = DEF_LEVEL;
  uint8 last_level_5 = DEF_LEVEL;
  uint16 delay_5 = DEF_DELAY;
  uint8 level_6 = DEF_LEVEL;
  uint8 last_level_6 = DEF_LEVEL;
  uint16 delay_6 = DEF_DELAY;
#endif
uint8 rfsw_1 = DEF_LEVEL;
uint8 rfsw_2 = DEF_LEVEL;
#ifdef HW_1P0
  uint8 rfsw_3 = DEF_LEVEL;
  uint8 rfsw_4 = DEF_LEVEL;
  uint8 rfsw_5 = DEF_LEVEL;
  uint8 rfsw_6 = DEF_LEVEL;
  uint8 rfsw_7 = DEF_LEVEL;
#endif
uint8 rfsw_1_pos = 1;
uint8 rfsw_1_lpos = 1;
uint8 rfsw_2_pos = 1;
uint8 rfsw_2_lpos = 1;
uint8 rfsw_3_pos = 1;
uint8 rfsw_3_lpos = 1;
uint8 rfsw_4_pos = 1;
uint8 rfsw_4_lpos = 1;
uint8 rfsw_5_pos = 1;
uint8 rfsw_5_lpos = 1;
uint8 rfsw_6_pos = 1;
uint8 rfsw_6_lpos = 1;
uint8 rfsw_7_pos = 1;
uint8 rfsw_7_lpos = 1;
uint8 relay_pos = 0;
uint8 relay2_pos = 0;
uint16 count1 = 0;
uint16 count2 = 0;
uint16 count3 = 0;
uint16 count4 = 0;
uint16 count5 = 0;
uint16 count6 = 0;
uint16 countrf = 0;
uint16 rfswdelay = RFSWDELAY;

//Initialize reference voltage with default until read out of EEPROM
#define REFAVALINIT 3096824.2f
volatile float REFAVAL = REFAVALINIT;
//EEPROM address for reference value: 1
#define REFAVALADDR 1
//Original ADC2I = 620.606
//Original ADC2V = 846.281
//Voltage reported / Voltage real * ADC2VxINIT orig = ADC2VxINIT new
//Voltage reads high => increase ADC2V value
//Current reads high => increase ADC2I value
//EEPROM address for USB2.0 voltage value: 1
#define ADC2V1ADDR 1
//EEPROM address for USB3.0 voltage value: 2
#define ADC2V2ADDR 2
//10k/18.1k -> 0-5.973V -> ADC/4096*5973 -> 
#define ADC2V1INIT 685.752f //5.008V = 7.235V
#define ADC2V2INIT 685.752f
//todo: reset adc2v2init during "l" calibration for storing correction factors
//EEPROM address for slot 1 current value: 3
#define ADC2I1ADDR 3
#define ADC2I1INIT 1241.212f //50m shunt
#define ADC2I2ADDR 4
#define ADC2I2INIT 1241.212f
//EEPROM address for buffer current value: 5
#define V12VADDR 5
#define V12VINIT 3.46436f //x/4096*3.3*1000*4.3
volatile float V122V = V12VINIT;
volatile float ADC2I1 = ADC2I1INIT;
volatile float ADC2V1 = ADC2V1INIT;
volatile float ADC2I2 = ADC2I2INIT;
volatile float ADC2V2 = ADC2V2INIT;
volatile float corr_factor = 1.0f;
#define TOFFS1 0.0f
#define TOFFS2 0.0f

uint32 adciref = 0;
float vusb2 = 0;
float iusb2 = 0;
float vusb3 = 0;
float iusb3 = 0;
uint16 v12v_i = 0;

//32 chars with /r/n + 8 corrections (e.g. 4 backspace + 4 chars)
#define MAXCHARS 40
char receivedChars[MAXCHARS];
boolean newData = false;

void recvWithStartEndMarkers() {
  static boolean recvInProgress = false;
  static byte ndx = 0;
  char startMarkers[] = {'t', '?', 'v', 's', 'o', 'r', 'z', 'l', 'm'};
  char endMarkers[] = {'\n', '\r'};
  char rc;

  // if (Serial.available() > 0) {
  while (Serial.available() > 0 && newData == false) {
    rc = Serial.read();
    if (rc == '\b')
      Serial.print("\b \b");
    else
      Serial.print(rc);
        
    if (recvInProgress == true) {
      //Serial.println("Receive in progress");
      if (rc == endMarkers[0] || rc == endMarkers[1]){
        //Serial.println("Received endMarker");
        receivedChars[ndx] = '\0'; // terminate the string
        /*Serial.print("ndx=");
          Serial.println(ndx);
          Serial.print("rc=");
          Serial.print(rc);*/
        recvInProgress = false;
        ndx = 0;
        newData = true;
      } 
      else if (rc == '\b') { //Backspace = do not increment character index, do not write new character
        /*Serial.println("Received BS");
        Serial.print("ndx=");
        Serial.println(ndx);
        Serial.print("rc=");
        Serial.print(rc);*/
        if (ndx == 0) {
          ndx = 0;
        }
        else {
          //receivedChars[ndx] = 0;
          ndx--;
        }
      }
      else {
        /*Serial.println("Received normal");
          Serial.print("ndx=");
          Serial.println(ndx);
          Serial.print("rc=");
          Serial.print(rc);*/
        receivedChars[ndx] = rc;
        ndx++;
        if (ndx >= MAXCHARS) {
          ndx = MAXCHARS - 1;
        }
      }
    }

    else if (rc == startMarkers[0] || rc == startMarkers[1] || rc == startMarkers[2] || rc == startMarkers[3]
             || rc == startMarkers[4] || rc == startMarkers[5] || rc == startMarkers[6] || rc == startMarkers[7] || rc == startMarkers[8]) {
      /*Serial.println("Received startMarker");
        Serial.print("ndx=");
        Serial.println(ndx);
        Serial.print("rc=");
        Serial.print(rc);*/
      recvInProgress = true;
      receivedChars[ndx] = rc;
      ndx++;
      if (ndx >= MAXCHARS) {
        ndx = MAXCHARS - 1;
      }
    }

    else if (rc == endMarkers[0] || rc == endMarkers[1]) {
      Serial.print("\r\n");
      Serial.print("> ");
    }
  }
}

unsigned int fast_atoi_leading_pos( const char * p )
{
    unsigned int x = 0;
    ++p;
    while (*p >= '0' && *p <= '9') {
        x = (x*10) + (*p - '0');
        ++p;
    }
    return x;
}

int fast_atoi_leading_neg( const char * p )
{
    int x = 0;
    bool neg = false;
    ++p;
    if (*p == '-') {
        neg = true;
        ++p;
    }
    while (*p >= '0' && *p <= '9') {
        x = (x*10) + (*p - '0');
        ++p;
    }
    if (neg) {
        x = -x;
    }
    return x;
}

void printMenu(uint8 menu2) 
{
  switch (menu2) {
    default:
      #ifdef BREADBOARD
      Serial.print("\r\n");
      Serial.println("> Select Mode:");
      Serial.println(">  RF Switch");
      Serial.println(">   r[1-2]");
      Serial.println(">  Relay (1=off, 2=on)");
      Serial.println(">   l[1-2]");
      Serial.println(">  Open Drain Output");
      Serial.println(">   o[1-2] l[level: 0 = open, 1 = low] d[delay, x0.1s]");
      Serial.println(">            def.0,                      def.10 (1s)");
      Serial.println(">  Cal R/W Mode");
      Serial.println(">   t[r/w] a[address: 0-999] d[data, unsigned int (0-65535)]");
      Serial.println(">  Version");
      Serial.println(">   v");
      Serial.println(">  Status");
      Serial.println(">   s");
      Serial.println(">  Soft Reset");
      Serial.println(">   z");
      Serial.println(">  Help (Prints this menu)");
      Serial.println(">   ?");
      Serial.print("\r\n");
      Serial.print("> ");
      break;
      #endif
      #ifdef HW_1P0
      Serial.print("\r\n");
      Serial.println("> Select Mode:");
      Serial.println(">  RF Switch");
      Serial.println(">   r[1-7]");
      Serial.println(">  USB 2.0 Power (1=off, 2=on)");
      Serial.println(">   l[1-2]");
      Serial.println(">  USB 3.0 Power (1=off, 2=on)");
      Serial.println(">   m[1-2]");
      Serial.println(">  Open Drain Output");
      Serial.println(">   o[1-6] l[level: 0 = open, 1 = low] d[delay, x0.1s]");
      Serial.println(">            def.0,                      def.10 (1s)");
      Serial.println(">  Cal R/W Mode");
      Serial.println(">   t[r/w] a[address: 0-999] d[data, unsigned int (0-65535)]");
      Serial.println(">  Version");
      Serial.println(">   v");
      Serial.println(">  Status");
      Serial.println(">   s");
      Serial.println(">  Soft Reset");
      Serial.println(">   z");
      Serial.println(">  Help (Prints this menu)");
      Serial.println(">   ?");
      Serial.print("\r\n");
      Serial.print("> ");
      break;
      #endif
  }
}

void parseOD(uint8 nArgs, char* args[], uint8* level_n, uint16* delay_n)
{
  uint8 i;
  int16 strVal = 0;
  
  //Set default charge current/voltage/cutoff
  *level_n = DEF_LEVEL;
  *delay_n = DEF_DELAY;

  Serial.print("\r\n");
  if(nArgs>1)
  {
    for(i=1; i<nArgs; i++)
    {
      switch (args[i][0])
      {
        case 'l':
          Serial.print("> Using level: ");
          strVal = fast_atoi_leading_pos(args[i]);
          if(strVal>1)
            strVal = 1;
          *level_n = strVal;
          Serial.println(*level_n);
          break;
        case 'd':
          Serial.print("> Using delay: ");
          strVal = fast_atoi_leading_pos(args[i]);
          if(strVal<MIN_DELAY)
            strVal = MIN_DELAY;
          else if(strVal>MAX_DELAY)
            strVal = MAX_DELAY;
          *delay_n = strVal;
          Serial.print(*delay_n*100);
          Serial.println("ms");
          break;
        default:
          break;
      }
    }
  }
  
  if(*level_n == DEF_LEVEL)
  {
    Serial.print("> Using def level: ");
    Serial.println(*level_n);
  }
  if(*delay_n == DEF_DELAY)
  {
    Serial.print("> Using def delay: ");
    Serial.print(*delay_n*100);
    Serial.println("ms");
  }
}

void parseRF(uint8 nArgs, char* args[], uint8* pos_n)
{
  uint8 i;
  int16 strVal = 0;
  
  //Set default charge current/voltage/cutoff
  *pos_n = DEF_RFPOS;

  Serial.print("\r\n");
  if(nArgs>1)
  {
    for(i=1; i<nArgs; i++)
    {
      switch (args[i][0])
      {
        case 'l':
          Serial.print("> Using position: ");
          strVal = fast_atoi_leading_pos(args[i]);
          if(strVal<1)
            strVal = 1;
          if(strVal>2)
            strVal = 2;
          *pos_n = strVal;
          Serial.println(*pos_n);
          break;
        default:
          break;
      }
    }
  }
  
  if(*pos_n == DEF_RFPOS)
  {
    Serial.print("> Using def position: ");
    Serial.println(*pos_n);
  }
}

void setup() {
  int i = 0;
  unsigned short int wData = 0, estatus = 0;
  
  Serial.begin(115200);
  pinMode(RFSW_1,OUTPUT);
  digitalWrite(RFSW_1,LOW);
  pinMode(RFSW_2,OUTPUT);
  digitalWrite(RFSW_2,LOW);
  pinMode(OD_1,OUTPUT);
  digitalWrite(OD_1,LOW);
  pinMode(OD_2,OUTPUT);
  digitalWrite(OD_2,LOW);
  pinMode(RELAY,OUTPUT);
  digitalWrite(RELAY,LOW);
  /*#define RFSW_1 PB13
    #define RFSW_2 PB15
    #define RFSW_3 PA9
    #define RFSW_4 PA15
    #define RFSW_5 PB4
    #define RFSW_6 PB6
    #define RFSW_7 PB7
    #define OD_1 PB12
    #define OD_2 PB14
    #define OD_3 PA8
    #define OD_4 PA10
    #define OD_5 PB3
    #define OD_6 PB5
    #define RELAY PB11 //USB2.0, 1=on, 0=off
    #define RELAY2 PB10 //USB3.0, 1=on, 0=off
    #define USB2ISNS PB1
    #define USB2VSNS PB0
    #define USB3ISNS PA7
    #define USB3VSNS PA6
    #define AIREF PA5
    #define V12V PA4
    #define TMP1 PA3
    #define TMP2 PA2
    #define AUXADC1 PA1
    #define AUXADC2 PA2
    #define AUXIO1 PB8
    #define AUXIO2 PB9
    #define AUXI13 PC13*/
  #ifdef HW_1P0
    pinMode(RFSW_3,OUTPUT);
    digitalWrite(RFSW_3,LOW);
    pinMode(RFSW_4,OUTPUT);
    digitalWrite(RFSW_4,LOW);
    pinMode(RFSW_5,OUTPUT);
    digitalWrite(RFSW_5,LOW);
    pinMode(RFSW_6,OUTPUT);
    digitalWrite(RFSW_6,LOW);
    pinMode(RFSW_7,OUTPUT);
    digitalWrite(RFSW_7,LOW);
    pinMode(OD_3,OUTPUT);
    digitalWrite(OD_3,LOW);
    pinMode(OD_4,OUTPUT);
    digitalWrite(OD_4,LOW);
    pinMode(OD_5,OUTPUT);
    digitalWrite(OD_5,LOW);
    pinMode(OD_6,OUTPUT);
    digitalWrite(OD_6,LOW);
    pinMode(RELAY2,OUTPUT);
    digitalWrite(RELAY2,LOW);
    pinMode(USB2ISNS, INPUT_ANALOG);
    pinMode(USB2VSNS, INPUT_ANALOG);
    pinMode(USB3ISNS, INPUT_ANALOG);
    pinMode(USB3VSNS, INPUT_ANALOG);
    pinMode(TMP1, INPUT_ANALOG);
    pinMode(TMP2, INPUT_ANALOG);
    pinMode(AUXADC1, INPUT_ANALOG);
    pinMode(AUXADC2, INPUT_ANALOG);
    pinMode(V12V, INPUT_ANALOG);
    pinMode(AIREF, INPUT_ANALOG);
    adciref = analogRead(AIREF); //Iref voltage
  #endif

  delay(5000);

  Timer2.pause(); // Pause the timer while we're configuring it
  Timer2.setPrescaleFactor(2);
  Timer2.setOverflow(36000); //36 MHz/36000 = 1000 Hz
  //Set up an interrupt on channel 1
  Timer2.setChannel1Mode(TIMER_OUTPUT_COMPARE);
  Timer2.setCompare(TIMER_CH1, 1);  // Interrupt 1 count after each update
  Timer2.attachCompare1Interrupt(handler_loop);
  Timer2.refresh(); //Refresh the timer's count, prescale, and overflow

  #ifdef BREADBOARD
  Serial.print("> HW Cfg: Breadboard");
  #endif
  #ifdef HW_1P0
  Serial.print("> HW Cfg: 1.0");
  #endif

  estatus = EEPROM.init();
  if(estatus != 0)
  {
    Serial.print("> EEPROM init err: ");
    Serial.println(estatus, HEX);
  }
  
  Serial.println("> Init cal from EEPROM");
  estatus = EEPROM.read(0, &wData);
  if(estatus == 0)
  {
    if(wData > 1000 || wData < 1) //ideal = 1.0556V
    {
      Serial.println("> RF switch delay out of range, using default.");
    }
    else
    {
      Serial.print("> RF switch delay value: ");
      Serial.print(wData);
      Serial.println("ms");
      RFSWDELAY = wData;
    }
  }
  else
  {
    Serial.println("> RF switch delay not found, using default.");
  }
  estatus = EEPROM.read(REFAVALADDR, &wData);
  if(estatus == 0)
  {
    if(wData > 2600 || wData < 2400)
    {
      Serial.println("> Ref cal out of range, using default.");
    }
    else
    {
      Serial.print("> Ref cal value: ");
      Serial.print(wData);
      Serial.println("mV");
      REFAVAL = ((float)wData)*1241.212;
    }
  }
  else
  {
    Serial.println("> Ref cal not found, using default.");
  }
  
  Serial.print("> SW ver: ");
  Serial.println(vers);

  Serial.println("> Init ref...");
  adciref = 0;
  for(i=0;i<1000;i++)
  {
    adciref += analogRead(AIREF); //Iref voltage
    //Serial.println(adciref);
  }
  Serial.print("> ADC corr: ");
  corr_factor = (REFAVAL/((float)adciref));
  Serial.print(corr_factor*100);
  Serial.print(" ");
  ADC2I1 = ADC2I1/corr_factor;
  Serial.print(ADC2I1);
  Serial.print(" ");
  ADC2I2 = ADC2I2/corr_factor;
  ADC2V1 = ADC2V1/corr_factor;
  Serial.println(ADC2V1);
  ADC2V2 = ADC2V2/corr_factor;
  adciref = (uint32)((float)adciref/1000.0); //Iref voltage
  
  Timer2.resume(); //Start the timer counting
}

void updateADCRef(){
  int i = 0;
  adciref = 0;
  for(i=0;i<1000;i++)
  {
    adciref += analogRead(AIREF); //Iref voltage
  }
  corr_factor = (REFAVAL/((float)adciref));
  ADC2I1 = ADC2I1/corr_factor;
  ADC2I2 = ADC2I2/corr_factor;
  ADC2V1 = ADC2V1/corr_factor;
  ADC2V2 = ADC2V2/corr_factor;
  adciref = (uint32)((float)adciref/1000.0); //Iref voltage
}
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

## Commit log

2020-04-05 Fixed ms printing
    Added level 0 notification in CLI when delay expires
    [stm32_usbrelay.ino]
2020-04-05 Fixed notification printing
    Fixed notification printing, cleaned up prompt printing after usage
    [stm32_usbrelay.ino]
2020-04-08 Added relay
2020-05-21 Changes for HW1.0
    Supports 6x OD outputs now, with generic parser (variables passed to it)
    Supports 7x RF switch outputs now, r1-r7 trigger command
    Supports 2nd relay now (USB2.0/3.0 power control), "m1/m2" command used
    Displays USB current/voltage when "s" status command used, displays 12V voltage also
    Added calibration/scaling based on voltage reference ADC measurement, EEPROM address 1 (2400-2600mV setting for real VREF voltage)
    Fixed printing of relay delay setting (1-1000ms) at startup
    Theoretically backwards compatible with "BREADBOARD" define instead of "HW_1P0" define
    [stm32_usbrelay.ino]

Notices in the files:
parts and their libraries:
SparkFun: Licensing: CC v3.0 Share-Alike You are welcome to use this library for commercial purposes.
